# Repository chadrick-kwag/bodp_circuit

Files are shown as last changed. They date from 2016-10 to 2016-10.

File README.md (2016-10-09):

# bodp_circuit
battery over discharge protection circuit project.
A blog post explaining the design background and measurement procedure and results is [here](https://kwagjj.wordpress.com/2016/10/09/battery-overdischarge-protection-circuit/). Please check this post to get a glimpse of what this circuit can do.

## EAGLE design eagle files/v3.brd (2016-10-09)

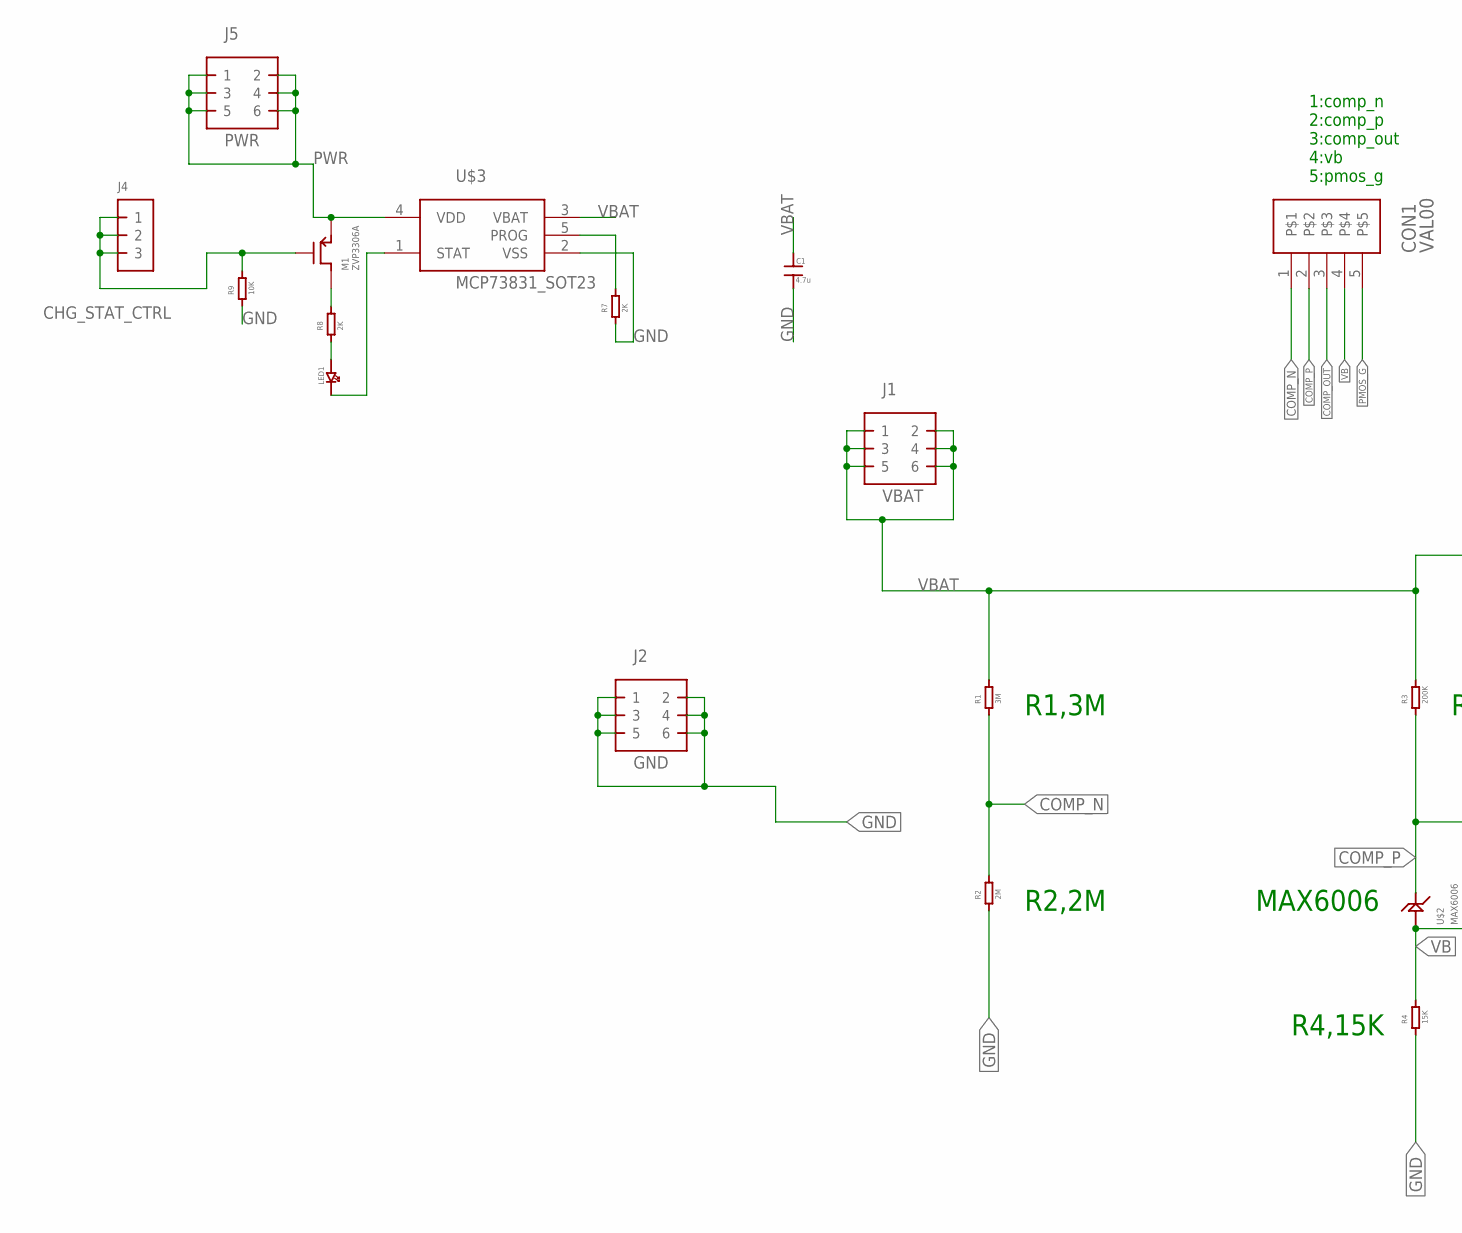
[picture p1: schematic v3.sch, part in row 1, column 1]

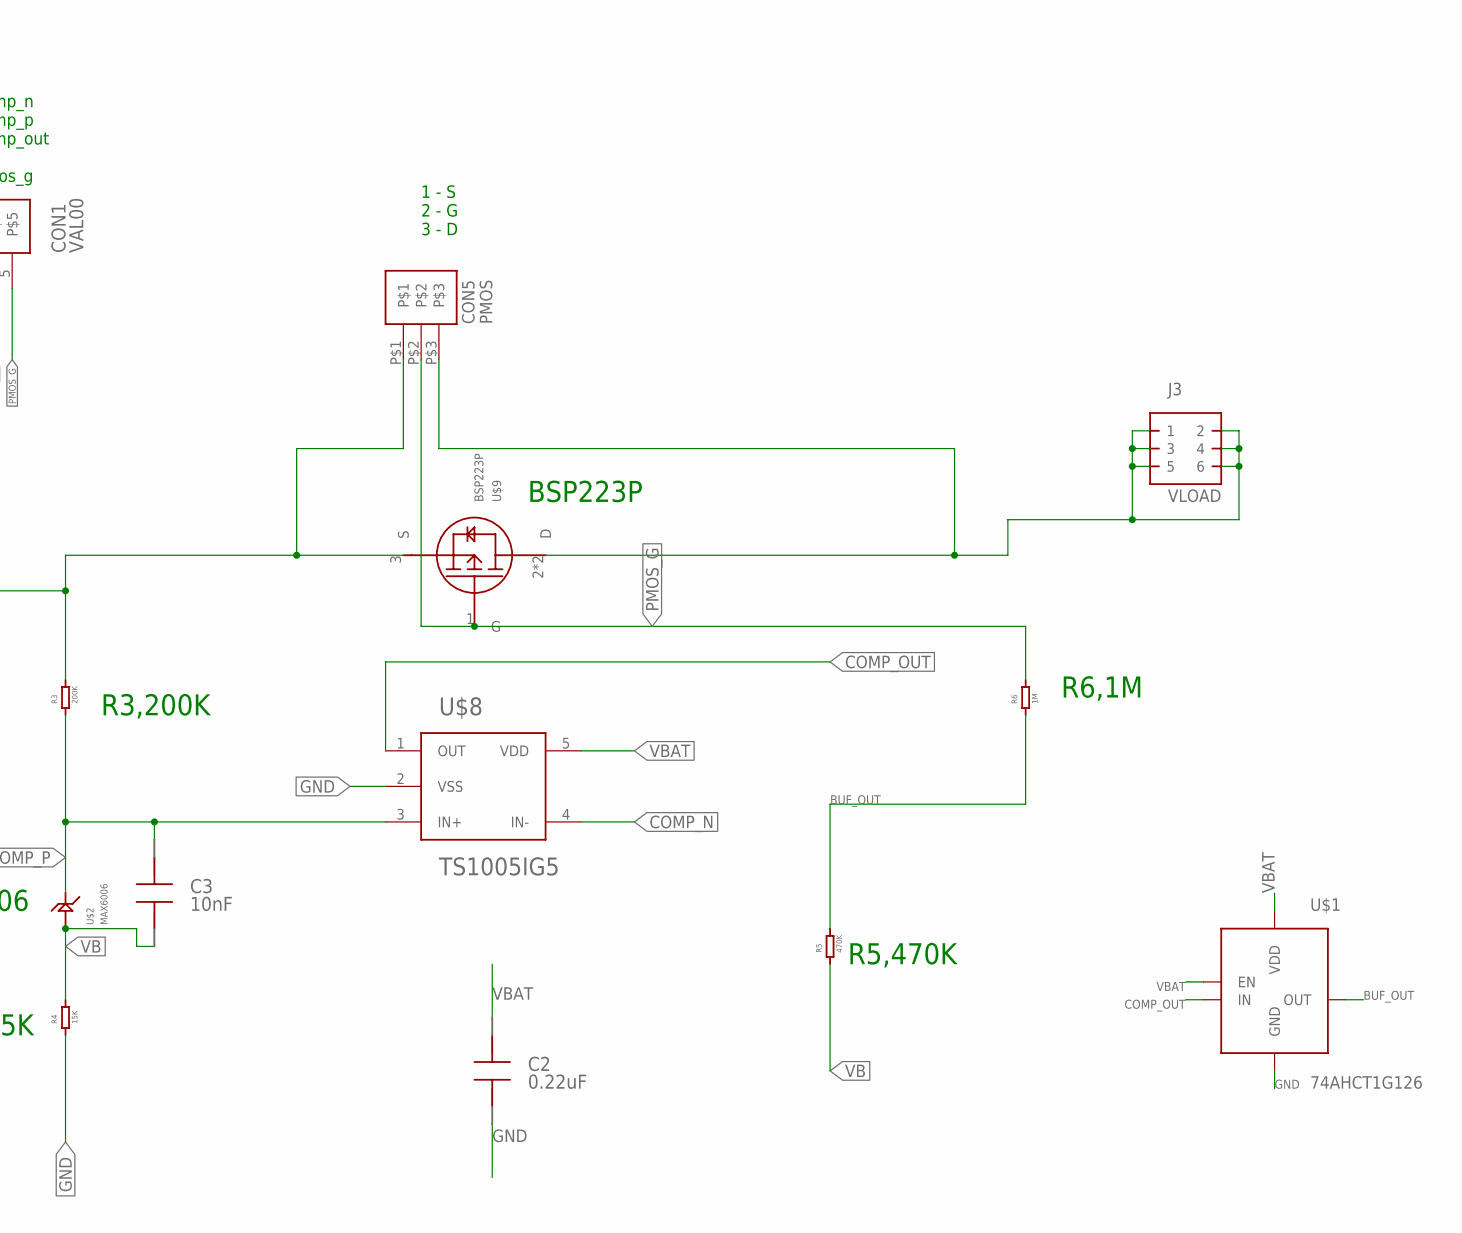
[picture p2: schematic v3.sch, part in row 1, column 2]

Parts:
C1: 4.7u; GRM21
C2: 0.22uF; UMK212F224ZD-T
C3: 10nF; WALSIN_CAP_0805(2012MM)
CON1: VAL00; 1X05_PH_2.54MM
CON5: PMOS; 1X03_PH_2.54MM
J1: VBAT; 2X3_2.54MM
J2: GND; 2X3_2.54MM
J3: VLOAD; 2X3_2.54MM
J4: 1X3_2.54MM
J5: PWR; 2X3_2.54MM
LED1: LG_R971-KN-1; LG_R971-KN-1_2012
M1: ZVP3306A; ZVP3306A-TO92_2.54MM
R1: 3M; ERJ2012
R2: 2M; ERJ2012
R3: 200K; ERJ2012
R4: 15K; ERJ2012
R5: 470K; ERJ2012
R6: 1M; ERJ2012
R7, R8: 2K; ERJ2012
R9: 10K; ERJ2012
U$1: 74AHCT1G126; 74AHCT1G126-SOT353
U$2: MAX6006; 8_SO_LP_90_0096
U$3: MCP73831_SOT23; MICROCHIP-SOT-23
U$8: TS1005IG5; SILICONLABS-SOT23-5-G5_CUSTOM_V1
U$9: BSP223P; INFINION-PG-SOT-223-4N

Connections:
BUF_OUT: R5.P$1 (1), R6.P$2 (2), U$1.4 (OUT)
CHG_STAT_CTRL: J4.P$1 (1), J4.P$2 (2), J4.P$3 (3), M1.G, R9.P$1 (1)
COMP_N: CON1.1, R1.P$2 (2), R2.P$1 (1), U$8.4 (IN-)
COMP_OUT: CON1.3, U$1.2 (IN), U$8.1 (OUT)
COMP_P: C3.P$1, CON1.2, R3.P$2 (2), U$2.6 (OUT), U$2.8 (OUT), U$8.3 (IN+)
GND: C1.P$2 (2), C2.P$2, J2.P$1 (1), J2.P$2 (2), J2.P$3 (3), J2.P$4 (4), J2.P$5 (5), J2.P$6 (6), R2.P$2 (2), R4.P$2 (2), R7.P$2 (2), R9.P$2 (2), U$1.3 (GND), U$3.2 (VSS), U$8.2 (VSS)
unnamed: LED1.A (CURRENT_IN), R8.P$2 (2)
unnamed: R7.P$1 (1), U$3.5 (PROG)
unnamed: CON5.P$3, J3.P$1 (1), J3.P$2 (2), J3.P$3 (3), J3.P$4 (4), J3.P$5 (5), J3.P$6 (6), U$9.2 (D), U$9.4 (D)
unnamed: LED1.C (CURRENT_OUT), U$3.1 (STAT)
unnamed: M1.D, R8.P$1 (1)
PMOS_G: CON1.5, CON5.P$2, R6.P$1 (1), U$9.1 (G)
PWR: J5.P$1 (1), J5.P$2 (2), J5.P$3 (3), J5.P$4 (4), J5.P$5 (5), J5.P$6 (6), M1.S, U$3.4 (VDD)
VB: C3.P$2, CON1.4, R4.P$1 (1), R5.P$2 (2), U$2.4 (GND)
VBAT: C1.P$1 (1), C2.P$1, CON5.P$1, J1.P$1 (1), J1.P$2 (2), J1.P$3 (3), J1.P$4 (4), J1.P$5 (5), J1.P$6 (6), R1.P$1 (1), R3.P$1 (1), U$1.1 (EN), U$1.5 (VDD), U$3.3 (VBAT), U$8.5 (VDD), U$9.3 (S)

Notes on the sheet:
1:comp_n 2:comp_p 3:comp_out 4:vb 5:pmos_g
1 - S 2 - G 3 - D
R1,3M
R2,2M
MAX6006
R4,15K
BSP223P
R6,1M
R5,470K
R3,200K

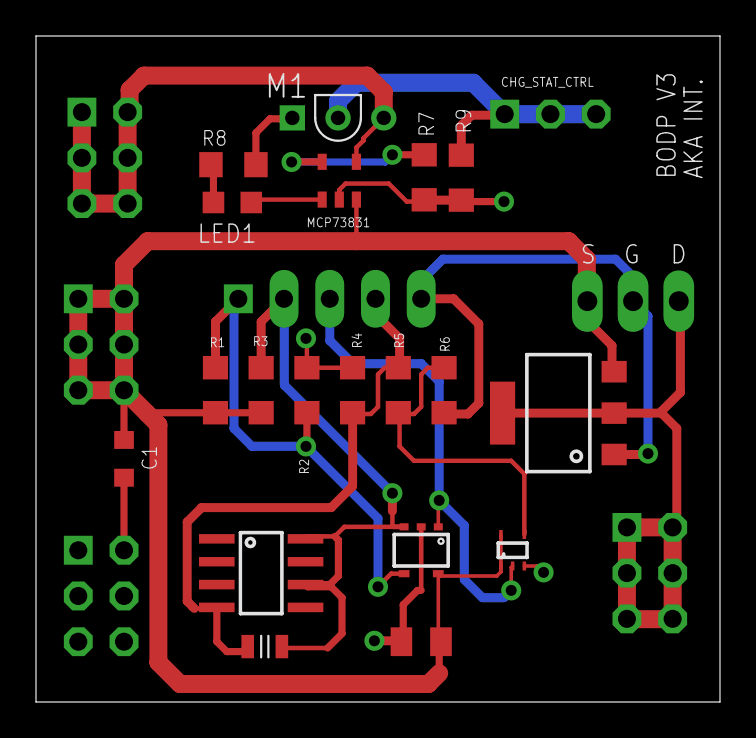
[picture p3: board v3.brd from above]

Board: 2 copper layers, 38.0 x 37.0 mm, 26 parts (0 on the bottom side), 15 nets.

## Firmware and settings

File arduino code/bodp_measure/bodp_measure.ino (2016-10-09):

/*
 * 
 * author: Chadrick Kwag
 * github: https://github.com/chadrick-kwag/bodp_circuit
 * GPL V3 licensed
 * version: 1.0
 */

int val = 0;           // variable to store the value read
float volt=0;

/* the analog reference voltage value. 
 * You can just put in value of 5, but if you want to be more precise, 
 * measuring the AREF votlage value with a multimeter and putting that 
 * value here is recommended. 
 */
float top=4.98; 
float measurement[4]={};

/*
 * you may change the period of data tranmission. the INTERVAL_SEC 
 * is in second unit.
 */
#define INTERVAL_SEC 10

int interval_msec=INTERVAL_SEC*1000;

int VBAT_pin=0;
int VLOAD_pin=1;
int PMOS_G_pin=2;
int COMP_P_pin=3;


void setup()

{
// using baudrate of 9600. Please keep this mind when setting up host
  Serial.begin(9600);        
  

}

void do_meas(void);
void send_meas(void);

/*
 * the main loop will just keep sending voltage measurements periodically.
 */
void loop()
{

  do_meas();
  send_meas();
  
  delay(interval_msec);

}

void do_meas(void){
  int i;
  for(i=0;i<4;i++){
    val=analogRead(i);
    volt=(float)val*top/1023;
    measurement[i]=volt;
  }
}

void send_meas(void){

  int i;
  for(i=0;i<4;i++){
    Serial.print(measurement[i]);
    Serial.print(';');
  }
  Serial.print('\n'); // add next line to make things easier for the host.
  
}

/*
 * end of code
 */

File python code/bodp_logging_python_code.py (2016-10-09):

'''
title: bodp_logging_python_code
author: chadrick kwag
update: 161009 (yymmdd)
version: 1.0
license: GPL V3
github: https://github.com/chadrick-kwag/bodp_circuit
description: 
this python code works with bodp arduino sketch code.
It will receive a string of measurements periodically.
This received string will be split accordingly and saved
in a text file to let the user easily process it when the
measurement is done. 

***CAUTION***
- please make sure that 'serial' library is installed.
- this code is for windows environment. The author has tested this code in Windows 10.
This python code works.
- Please change the COM number to match the arduino connected to your computer.
- currently, if you want to stop logging, press Ctrl+C to kill python code.
Its not a neat way of doing things, but it works.
'''


'''
int VBAT_pin=0;
int VLOAD_pin=1;
int PMOS_G_pin=2;
int COMP_P_pin=3;
'''


import serial
import os.path
import sys


def slicing(inputstr):
    list1=inputstr.split(';')
    newstr=""
    for i in range(0,len(list1)):
        if i is len(list1)-1:
            newstr=newstr+list1[i]
        else:
            newstr=newstr+list1[i]+'\t'

    newstr=newstr+'\n' # erase last \t
    return newstr

    
### prepare naming of log file
SAVEFILENAME_PREFIX="BODP_DISCHARGE_LOG_"
SAVEFILENAME_END=".txt"

savefilename=""

# currently, I've just limited the log file number to 10.
# This menas that if the number of log files generated reaches 10,
# the user will have to remove some in order to make room for
# new log files to be created. You can change this here.
for i in range(0,10):
    savefilename=SAVEFILENAME_PREFIX+str(i)+SAVEFILENAME_END;
    if os.path.isfile(savefilename) is False:
        print("savefile: "+savefilename)
        break
    if i==9:
        sys.exit()




### serial operation

# please change COM14 to the one that fits to your situation!!!
# if you have changed the arduino code's baudrate, please change it here as well!
ser=serial.Serial('COM14',9600,timeout=0,bytesize=serial.EIGHTBITS,parity=serial.PARITY_NONE)

print(ser.name)
print(ser.isOpen())

readstr=""

while 1:
    if ser.inWaiting() > 0:
        rawreadval=ser.read(1)
        readval=chr(int.from_bytes(rawreadval,byteorder='big'))
        #print(readval)
        readstr=readstr+readval

        if readval is '\n':
            print(readstr)
            str2=slicing(readstr[:-1]) # erase the last \n when passing
            fd=open(savefilename,"a")
            fd.write(str2)
            fd.close()
            readstr=""

            
            

ser.close()

### end of code
